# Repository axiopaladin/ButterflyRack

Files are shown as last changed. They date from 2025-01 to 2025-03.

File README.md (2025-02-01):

# ButterflyRack
A modular, 3D printed frame for attaching metal rails!

This is a simple 3D-printable design for homemade server racks. It was 
initially designed for 10" racks, per 
[Jeff Geerling's Project Mini-Rack](https://github.com/geerlingguy/mini-rack) 
initiative, but in theory it could be extended to any width (including 19") if 
a butterfly of the appropriate length is used instead of the 2113 shown here.

## Why "Butterfly"?
A key feature of this design is its use of symmetry. Dovetail joints are used 
fix corner brackets together with a modular spacer, but since all corners are 
mirrors of each other, they all have identical dovetail pins. Two identical 
openings cannot be mated without a middle piece called a *butterfly*, which has 
the corresponding "tail" on *both* sides. These modular butterfly spacers can 
easily be extended to any length, making it very simple to build a rack with 
arbitrary depth or width. The height of the rack is determined by the length of 
the rails chosen: the minimum size is 2U, and there is no maximum.

## Bill of Materials
### Printed Parts
 - (4x) Corner Bracket
 - (4x) Mirrored Corner Bracket
 - (4x) 2113mil Butterfly (for a 10" rack)
 - (4x) Butterfly (choose depending on desired depth)

### Hardware
 - (4x) Server Rack Rails (e.g. [these 8U rails](https://www.amazon.com/dp/B00JQYUEA2))
 - (16x) M6x16mm Bolts
 - (16x) M6 Nuts

## Build Instructions

 1. Print all the necessary parts. **Do not forget to mirror half of the** 
**corner brackets in your slicer. They are chiral.** One set of four 2113mil 
butterflies is necessary to fix the width at 10", whereas the second set of 
four butterflies determine the rack's depth and can be any length. Using 
2113mil butterflies again will make a rack that is 10" deep. The other 
pre-made butterflies in this repository are 0mil, which would make a rack that 
is approximately 8" deep, comparable to the 
[DeskPi Rackmate](https://deskpi.com/collections/deskpi-rack-mate). A 
250mm-class printer like the Bambu X1 Carbon can print all 16 parts in just 
two jobs. Smaller printers can still do the job, however; the longest dimension 
of any printed part is just 4.5 inches.

 2. Press-fit four corner brackets together with four butterfly joints. A 
well-calibrated printer should produce parts that fit extremely tightly, but a 
drop of glue or epoxy could be added for peace of mind, if desired. Note that 
identical corner brackets should always be diagonal from one another, never 
adjacent. An example photo is shown below, with each part color-coded:
   - **Red** parts are **standard corner brackets**
   - **Black** parts are the **_mirrored_ corner brackets**
   - **Blue** parts are **2113mil butterflies**, notice how they are aligned 
perpendicularly with the "flat" face of the corner brackets' uprights.
   - **Yellow** parts are the **depth butterflies**, 2113mil in this example.

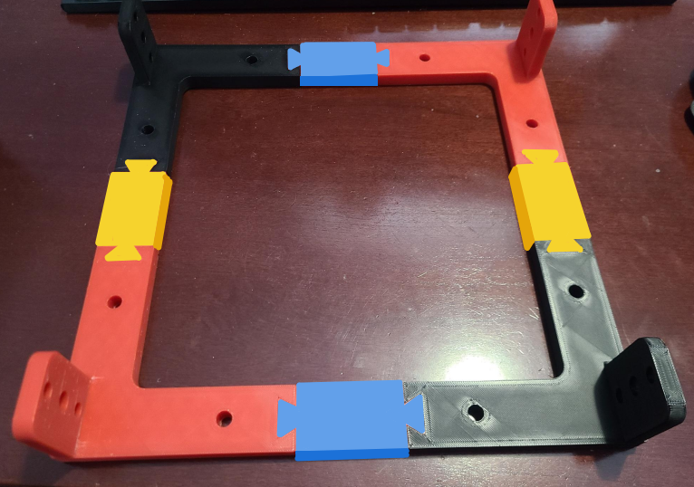
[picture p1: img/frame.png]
An image depicting the assembly of the printed parts. Clockwise, from top-leftt: mirrored corner bracket (MCB), 2113 butterfly (WB), standard corner bracket (SCB), depth butterfly (DB), MCB, WB, SCB, DB.


 3. Using a pair of M6 bolts and corresponding nuts, bolt one rail to each 
corner of the assembled plastic frame. The rail will sit flush with the top 
surface of the corner bracket; you may have to apply some force to make the 
lower hole in the bracket's upright align properly. The friction from the tight 
fit should prevent the need for lock nuts, but a drop of thread adhesive could 
be added if the rack is expected to regularly experience heavy vibration. The 
image below uses the same color scheme as above.

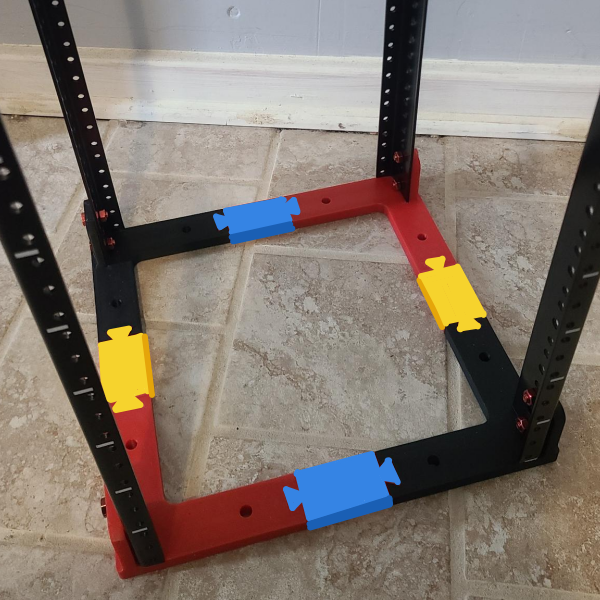
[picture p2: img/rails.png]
An image showing 8U rails affixed to all four corners of the printed frame.


 4. Repeat step 2 with the remaining printed parts and then attach the second 
frame to the other end of the rails the same as in step 3, capping off the 
rack. Congratulations, it is now complete and ready for you to add your 
rack-mount equipment!

## Accessories & Extras
### Carry Handles
I've added a pair of handles to my rack. Those 8mm holes in the angle brackets 
aren't just there to add extra walls to the middle of the arm: they're 
secretly just the right size for M6 heated inserts! This allows us to attach 
items along the frame, so long as they have a pair of holes that match the 
distance given by the butterfly spacer, with nothing but some spare M6 bolts.

#### Printed Parts
 - (2x) Handle2113 (for use along axes with a 2113mil Butterfly spacer)

#### Hardware 
 - (4x) M6 Heated Inserts (8mm OD, 8mm depth)
 - (4x) M6 x 16mm Bolts

#### Assembly Instructions
 1. Flip the rack upside-down and set out the heatset inserts as shown below:

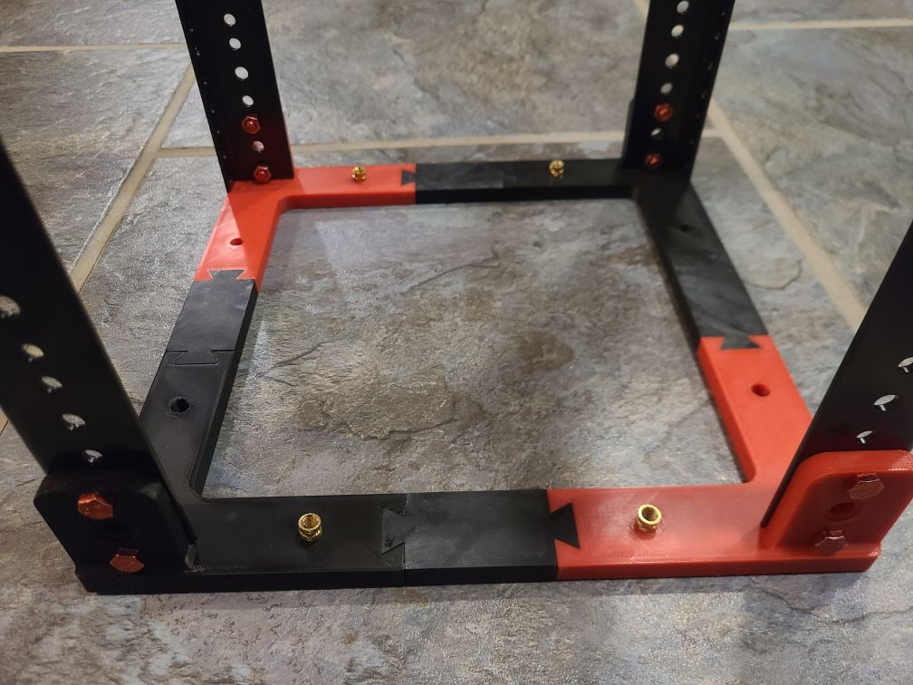
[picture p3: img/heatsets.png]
An image showing four heatset inserts in the holes lined up between the front and back rails on each side.


 2. Using your preferred heating tool, heat up each insert and press it down 
until it seats flush. (Tip: Press it most of the way down with heat, then 
press it the rest of the way with a large, flat object to prevent 
over-penetration.)

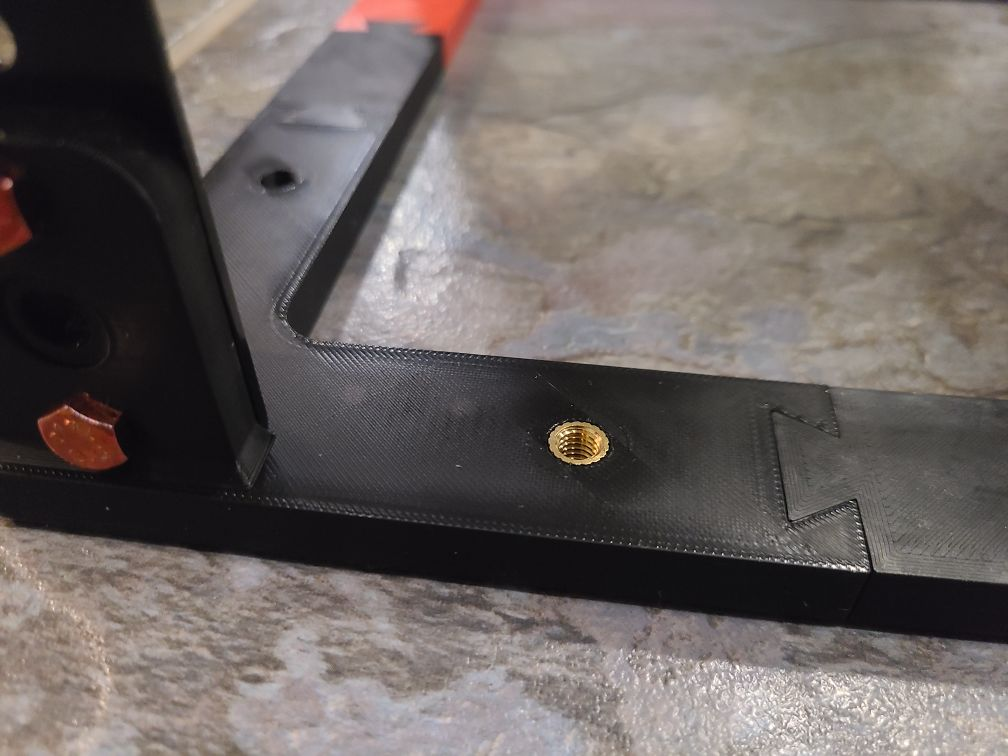
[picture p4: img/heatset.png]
An image showing a properly inserted heatset.


 3. Flip the rack back over (upside-up) and screw the handles in place with the 
M6 bolts. (The bolts should be screwing into the heatset inserts from the 
*opposite* side of the one they were inserted from.)

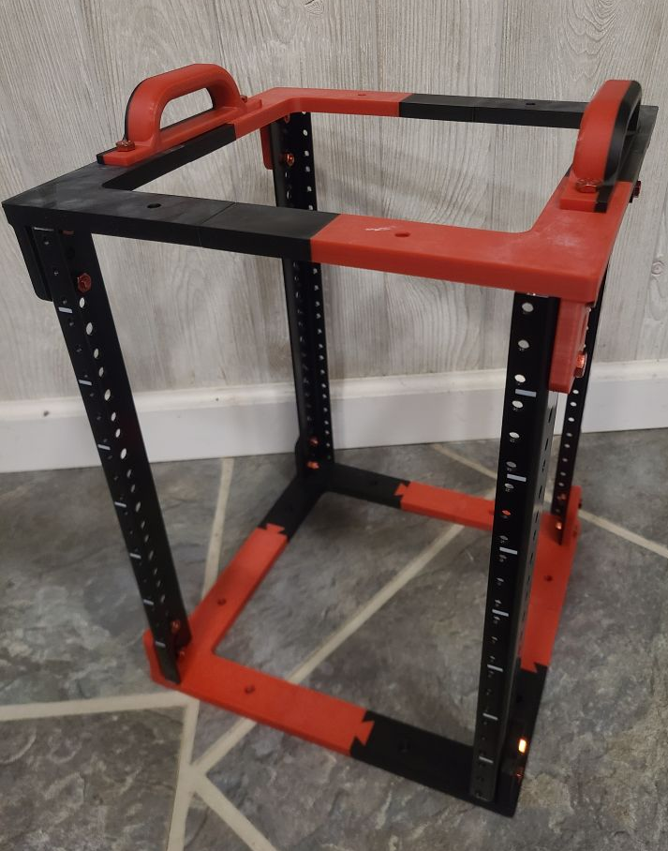
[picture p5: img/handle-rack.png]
An image showing the completed rack, with handles attached.


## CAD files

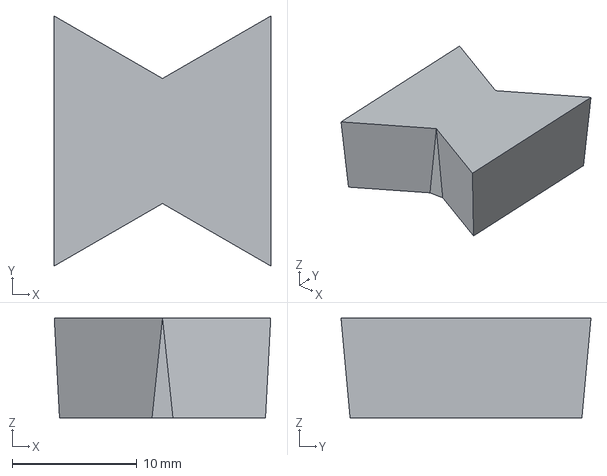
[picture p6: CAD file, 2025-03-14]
STEP/Butterfly0000.step
17.3 x 20.0 x 8.00 mm

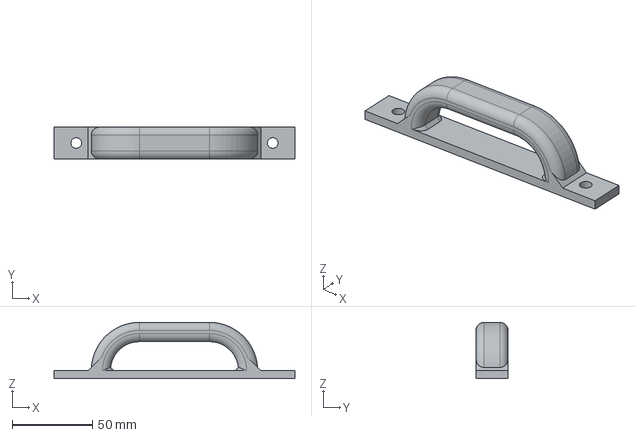
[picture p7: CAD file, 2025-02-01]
STEP/Handle2113.step
150.0 x 20.0 x 35.0 mm

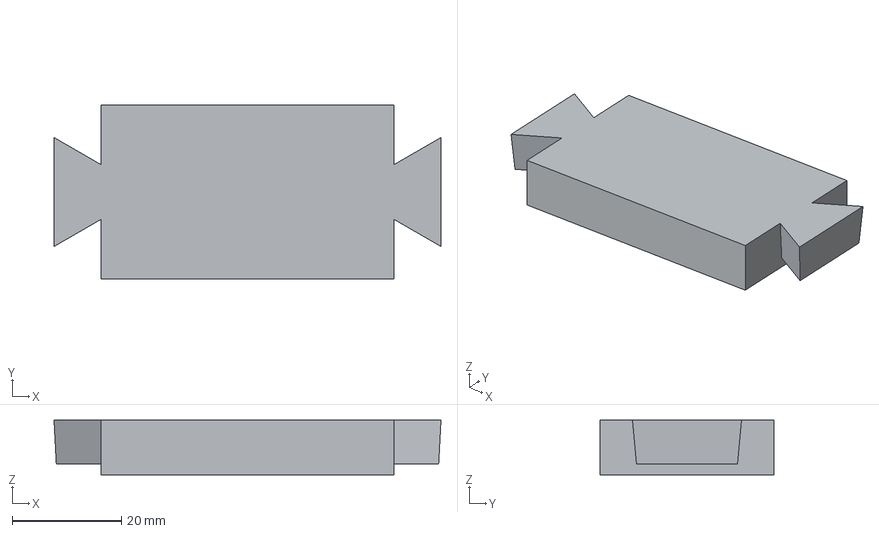
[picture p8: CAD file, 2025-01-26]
STEP/Butterfly2113.step
71.0 x 32.0 x 10.0 mm

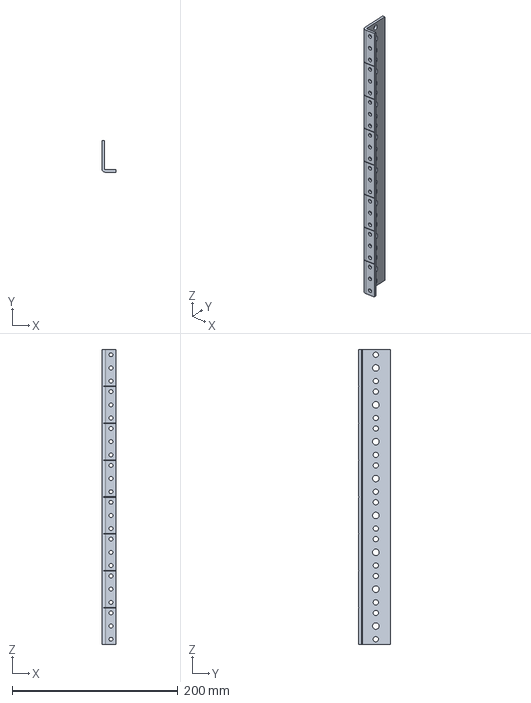
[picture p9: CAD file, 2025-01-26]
STEP/REFERENCE-NOPRINT-Rail8U.step
17.5 x 38.1 x 355.6 mm

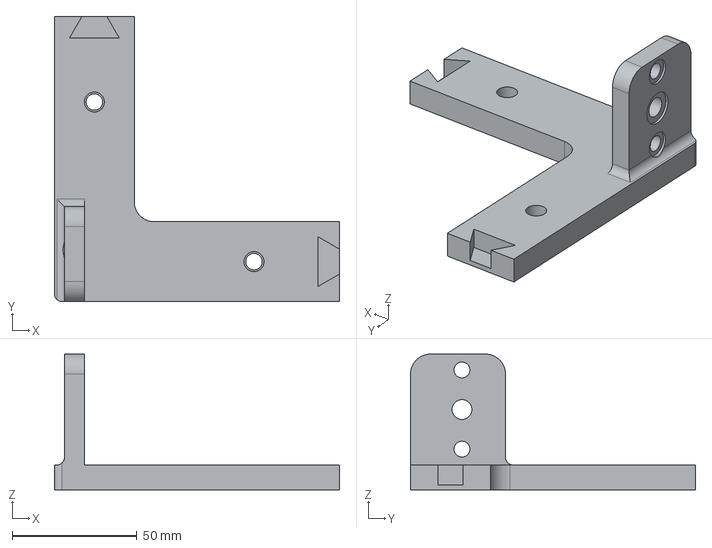
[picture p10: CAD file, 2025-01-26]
STEP/CornerBracket.step
114.3 x 114.3 x 54.5 mm

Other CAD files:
FreeCAD/Butterfly0000.FCStd
FreeCAD/Butterfly2113.FCStd
FreeCAD/CornerBracket.FCStd
FreeCAD/Handle2113.FCStd

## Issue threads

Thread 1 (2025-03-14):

Butterfly0000 butterfly incorrect size

cblanos, 2025-03-14:
Love this project, and I've printed and built a rack using the Butterfly2113.step butterflies. Everything fits together as intended - fantastic job!

Since my equipment isn't all that deep, I was going to update using the Butterfly0000.step butterfly to reduce the depth but noticed that they are much taller than Butterfly2113.step. I didn't print yet, but it does not look like they'll fit as intended.

I did not install FreeCad to check the FCStd file, and wanted to ask if you could confirm the sizing of the Butterfly0000.step file.

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

axiopaladin, 2025-03-14:
Good catch! I threw that 0000 design together without ever printing any out to test them myself, so it's probably a design error on my part. I just pushed a quick-and-dirty update that *should* fix it, but please let me know if this newer shorter version doesn't fit either. And when you've finished putting yours back together I'd love to see a photo!

cblanos, 2025-03-15:
The new 0000 part works great! I did scale it up a very small amount (100.75%) just to snug up the fit, but that's to account for my filament, printer, etc. Thank you for the quick update!

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

axiopaladin, 2025-03-17:
Awesome! Glad to hear it works, and the setup in your photo looks great!

Closed 2025-03-17.

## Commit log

2025-01-26 Version 1.0 + added STEP files + added manual with photos
    [Butterfly0000.step, Butterfly2113.step, CornerBracket.step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]
2025-02-01 Added FreeCAD files
    [Butterfly0000.FCStd, Butterfly2113.FCStd, CornerBracket.FCStd]
2025-02-01 Added carry handle FreeCAD, STEP, and assembly docs
    [Handle2113.FCStd, Handle2113.step]
2025-03-14 Fixed height of Butterfly0000 to 8mm
    [Butterfly0000.FCStd, Butterfly0000.step]
